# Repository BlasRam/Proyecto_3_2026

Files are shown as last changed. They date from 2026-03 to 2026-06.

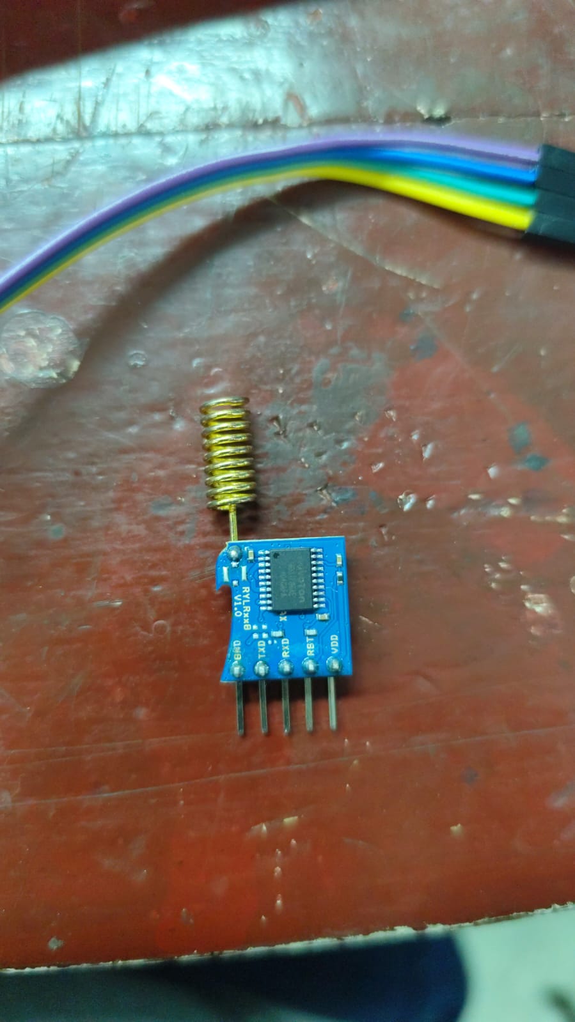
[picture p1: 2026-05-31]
Sistema_IAQ_LoRa/Sistema_IAQ_LoRa/images/2.jpeg

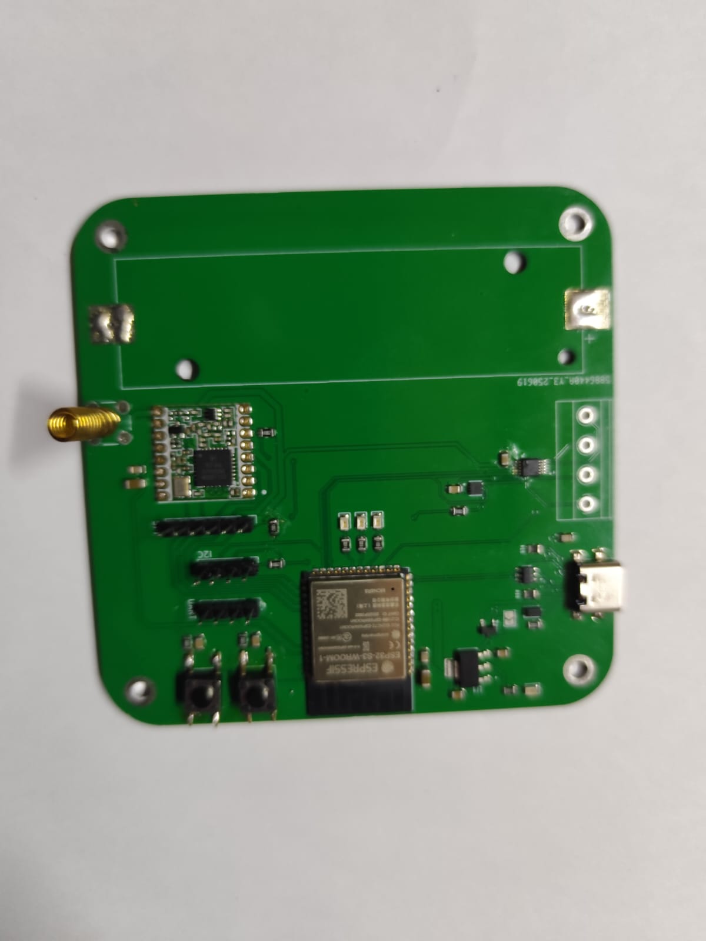
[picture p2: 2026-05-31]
Sistema_IAQ_LoRa/Sistema_IAQ_LoRa/images/4.jpeg

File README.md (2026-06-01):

# Sistema Experimental para el Monitoreo de la Calidad del Aire Interior (IAQ) y Variables Ambientales con Comunicación LoRa

## Descripción

Este repositorio contiene el desarrollo de un sistema experimental para el monitoreo de la calidad del aire interior (IAQ) y variables ambientales, con capacidad de comunicación inalámbrica mediante tecnología LoRa.

El proyecto está orientado al diseño y validación de una plataforma electrónica basada en **ESP32-S3**, integrando sensado ambiental, adquisición de señales, supervisión energética y transmisión de datos. La propuesta busca servir como base para futuras pruebas de hardware, adquisición de datos ambientales y validación de un sistema completo de monitoreo IAQ.

## Objetivo

Desarrollar una plataforma experimental capaz de:

- monitorear variables asociadas a la calidad del aire interior
- adquirir variables ambientales complementarias
- supervisar el estado energético del sistema
- transmitir información de manera inalámbrica mediante LoRa
- servir como base para futuras etapas de validación y escalabilidad

## Características principales

- Microcontrolador **ESP32-S3**
- Monitoreo de calidad del aire interior (**IAQ**)
- Medición de variables ambientales
- Comunicación **LoRa**
- Supervisión de batería y alimentación
- Diseño electrónico propio en desarrollo
- Arquitectura modular y escalable

## Estado del proyecto

Actualmente el proyecto se encuentra en etapa de:

- desarrollo del esquemático electrónico
- selección e integración de componentes
- definición de arquitectura de alimentación y comunicaciones
- preparación para diseño de PCB
- consolidación del prototipo experimental

## Arquitectura general

El sistema contempla los siguientes bloques principales:

- **Unidad de control:** ESP32-S3
- **Sensado ambiental e IAQ:** sensores para calidad del aire y variables ambientales
- **Comunicación inalámbrica:** módulo LoRa
- **Supervisión energética:** monitoreo de batería y consumo
- **Alimentación:** entrada USB, batería recargable y regulación de voltaje
- **Expansión:** puertos auxiliares para futuras integraciones

## Tecnologías y módulos considerados

Dependiendo de la iteración del prototipo, el sistema contempla o evalúa componentes como:

- **ESP32-S3-WROOM-1**
- **RFM95CW** o **RYLR998** para comunicación LoRa
- **ENS160 / AHT2X** para IAQ y variables ambientales
- **ADS1015** para adquisición analógica adicional
- **MAX17048** para monitoreo de batería
- **TP4056** para carga de batería
- reguladores de 3.3 V para alimentación estable del sistema

## Estructura del repositorio

```text
/
├── Software/          # Programacion (Codigos y Pruebas) del proyecto
├── docs/              # Documentación del proyecto
├── hardware/          # Esquemáticos, PCB, librerías y archivos de diseño
├── firmware/          # Código fuente del microcontrolador
├── images/            # Diagramas, capturas y recursos gráficos
├── datasheets/        # Hojas de datos de los componentes utilizados
└── README.md          # Descripción general del proyecto

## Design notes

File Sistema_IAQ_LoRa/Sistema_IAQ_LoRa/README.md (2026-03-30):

# Sistema Experimental para el Monitoreo de la Calidad del Aire Interior (IAQ) y Variables Ambientales con Comunicación LoRa

## Descripción
Este repositorio contiene el desarrollo de un sistema experimental para el monitoreo de la calidad del aire interior (IAQ) y variables ambientales, con capacidad de comunicación inalámbrica mediante tecnología LoRa.

El proyecto está orientado al diseño y validación de una plataforma electrónica basada en ESP32-S3, integrando sensado ambiental, adquisición de señales, supervisión energética y transmisión de datos. La propuesta busca servir como base para futuras pruebas de hardware, adquisición de datos ambientales y validación de un sistema completo de monitoreo IAQ.

## Estructura del repositorio
```text
.
├── docs/                # Documentación del proyecto
├── hardware/            # Esquemáticos, PCB, librerías y archivos de fabricación
│   ├── kicad/           # Proyecto principal de KiCad
│   ├── libraries/       # Footprints, símbolos y modelos 3D adicionales
│   └── manufacturing/   # Archivos de producción (Gerbers, BOM, posiciones, etc.)
├── firmware/            # Código fuente del microcontrolador
├── images/              # Diagramas, capturas y recursos gráficos
├── datasheets/          # Hojas de datos de los componentes utilizados
└── README.md            # Descripción general del proyecto
```

## Integrantes
- Blas Antonio Ramirez Benitez
- Pedro Daniel Vera Ramirez
- Pablo Junior Otazu Lujan

## Estado del proyecto
Actualmente el proyecto se encuentra en etapa de desarrollo del prototipo electrónico, consolidación del esquemático y organización de los archivos de diseño para futuras pruebas y fabricación.

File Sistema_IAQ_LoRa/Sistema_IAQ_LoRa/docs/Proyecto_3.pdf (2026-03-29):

## Universidad Nacional de Asunción Facultad de Ingeniería Carrera de Ingeniería Mecatrónica

## Proyecto 3

# Sistema Experimental para el Monitoreo de la Calidad del Aire Interior (IAQ) y Variables Ambientales con Comunicación LoRa

### Integrantes

### Blas Antonio Ramirez Benitez

### Pedro Daniel Vera Ramirez

### Pablo Junior Otazu Lujan

Octavo semestre

## Resumen ejecutivo

El presente proyecto plantea el desarrollo de un sistema experimental orientado al monitoreo de la calidad del aire interior (Indoor Air Quality, IAQ), integrando sensado ambiental, adquisición de señales, supervisión energética y comunicación inalámbrica. La versión actual del prototipo se basa en un microcontrolador ESP32-S3-WROOM-1-N4R2 como núcleo de control, acompañado por un transceptor LoRa RFM95CW para comunicación inalámbrica, un convertidor analógico-digital ADS1015 para ampliar la capacidad de lectura de señales analógicas, un monitor de batería MAX17048 y una arquitectura de alimentación que incluye entrada USB-C, conmutación USB-batería y regulación LDO a 3.3 V.

Además de la configuración actual, el proyecto contempla como configuración final prevista la incorporación del sensor ENS160/AHT2X para medición de variables relacionadas con la calidad del aire interior, así como la posibilidad de utilizar un módulo RYLR998 como alternativa de comunicación LoRa en caso de no disponer del transceptor actualmente seleccionado. El trabajo se encuentra en etapa de consolidación del prototipo electrónico, con esquemáticos organizados por bloques y una estimación preliminar de costos. Los resultados esperados incluyen la obtención de una plataforma funcional, compacta y escalable que permita realizar futuras pruebas físicas, adquirir datos ambientales y servir como base para validaciones posteriores del sistema.

## Abstract

Este proyecto presenta el desarrollo de un sistema experimental para el monitoreo de la calidad del aire interior (IAQ), integrando sensado ambiental, adquisición de señales, supervisión energética y comunicación inalámbrica. El prototipo actual está basado en un microcontrolador ESP32-S3-WROOM-1-N4R2 como unidad principal de control, junto con un transceptor LoRa RFM95CW para comunicación inalámbrica, un convertidor analógico-digital ADS1015 para ampliar la adquisición de señales analógicas, un monitor de batería MAX17048 y una arquitectura de alimentación que incluye entrada USB-C, conmutación entre USB y batería, y regulación a 3.3 V mediante un regulador LDO.

Además de la configuración actual, el sistema final previsto contempla la integración de un sensor ENS160/AHT2X para la medición de la calidad del aire interior y de variables ambientales, así como la posibilidad de utilizar un módulo RYLR998 como solución LoRa alternativa en caso de que el transceptor originalmente seleccionado no esté disponible. En la actualidad, el proyecto se encuentra en la fase de prototipado electrónico y consolidación del esquemático, con los bloques funcionales ya definidos y una estimación preliminar de costos disponible. El resultado esperado es una plataforma compacta y escalable, capaz de servir como base para futuras pruebas de hardware, adquisición de datos ambientales y posterior validación del sistema completo de monitoreo IAQ.

## Estado del arte

Los sistemas de monitoreo de calidad del aire interior basados en IoT combinan habitualmente sensores de bajo costo, microcontroladores y enlaces inalámbricos para obtener datos en tiempo real y mejorar el control ambiental en espacios cerrados.

Marques y Pitarma presentan una revisión de sistemas IAQ para entornos inteligentes y resaltan la importancia de integrar sensado, procesamiento y comunicación en plataformas compactas [1].

Mota et al. desarrollan una arquitectura IoT para supervisión de IAQ, mostrando que los sistemas embebidos conectados son adecuados para monitoreo continuo en interiores [2].

González et al. validan el uso de LoRa en redes de sensores ambientales y de detección de eventos, respaldando su empleo cuando se requieren enlaces de largo alcance y bajo consumo [3].

Pietraru et al. analizan sensores MOS para VOC/TVOC en ambientes interiores y muestran que son apropiados como indicadores indirectos de calidad del aire dentro de arquitecturas experimentales o aplicadas [4].

Por su parte, la familia ENS160 ha sido desarrollada específicamente para aplicaciones IAQ y ofrece variables procesadas como eCO2, TVOC e índices de calidad del aire [5].

## Descripción

El proyecto consiste en el diseño de una plataforma experimental de monitoreo de calidad del aire interior, concebida como una base electrónica escalable para adquisición de variables ambientales, supervisión de señales analógicas, monitoreo energético y transmisión inalámbrica. El núcleo actual del sistema es el ESP32-S3-WROOM-1-N4R2, encargado de coordinar la lectura de periféricos y gestionar las interfaces de comunicación.

La versión prototipo actual contempla los bloques MCU, LoRa, ADC externo, monitor de batería, alimentación USB-batería, regulador, botones de control, LEDs de depuración y puertos de expansión. Como evolución prevista del sistema, se integrará un módulo ENS160/AHT2X para medir variables asociadas a calidad del aire interior y variables ambientales. En cuanto a la comunicación, se mantiene el uso actual del RFM95CW como transceptor LoRa, pero se considera al RYLR998 como alternativa viable de implementación si el componente principal no se encuentra disponible.

La motivación del proyecto radica en disponer de una plataforma propia para estudiar y experimentar con monitoreo IAQ, permitiendo tanto el aprendizaje en diseño electrónico como la futura validación de un sistema real de adquisición y transmisión de datos ambientales.

## Objetivos

General

Diseñar e implementar un sistema experimental de monitoreo de la calidad del aire interior (IAQ) mediante sensor MOS y variables ambientales, con capacidad de adquisición, supervisión energética y transmisión inalámbrica de datos.

Específicos

- Diseñar la arquitectura electrónica del sistema, incluyendo bloques de alimentación, control, adquisición y comunicación.
- Integrar un ESP32-S3 con periféricos externos para lectura de señales analógicas, monitoreo de batería y comunicación inalámbrica.
- Implementar una arquitectura de alimentación con batería recargable, entrada USB-C, selección de fuente y regulación estable a 3.3 V.
- Preparar el sistema para la futura integración del sensor ENS160/AHT2X y para la evaluación de módulos LoRa alternativos según disponibilidad.
- Desarrollar el prototipo electrónico como base para la futura fabricación de la PCB y la posterior etapa de pruebas físicas e integradas.

## Esquema general del proyecto

La Figura 1 muestra el esquema general del prototipo actual y la configuración final prevista. La arquitectura organiza el sistema en bloques funcionales: entrada USB-C, selector USB-batería, regulación a 3.3 V, MCU, comunicación LoRa, adquisición analógica, monitor de batería, puertos de expansión y módulo IAQ previsto para la versión final.

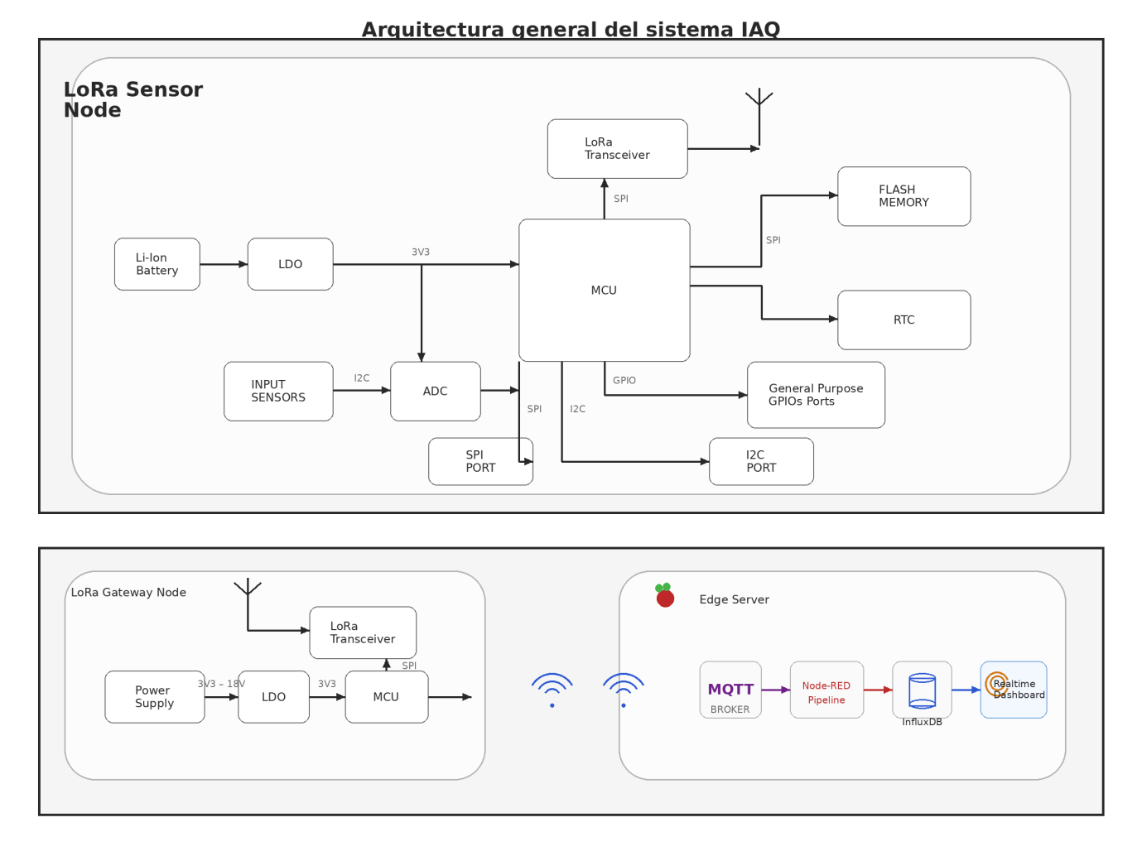
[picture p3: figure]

Figura 1. Esquema general del prototipo y configuración final prevista.

## 6.1 Product Breakdown Structure

1. Bloque MCU: ESP32-S3-WROOM-1-N4R2, alimentación a 3.3 V, USB nativo, botones de control y LEDs.
2. Bloque LoRa: RFM95CW como solución actual de comunicación y RYLR998 como alternativa contemplada.
3. Bloque de adquisición: ADS1015 para ampliación de entradas analógicas y puertos de expansión I2C/UART/SPI.
4. Bloque de monitoreo energético: MAX17048 para supervisión del estado de la batería.
5. Bloque de alimentación: USB-C, selector USB-batería, batería y regulador LDO a 3.3 V.
6. Bloque de sensado futuro: Integración prevista del módulo ENS160/AHT2X para IAQ y variables ambientales.

## Diseños

Electrónico

El diseño electrónico está organizado por bloques, lo que permite separar claramente funciones de alimentación, adquisición, comunicación y control. La Figura 2 presenta el bloque MCU, donde el ESP32-S3 se alimenta a 3.3 V, incorpora desacoples locales y expone líneas para comunicación LoRa, I2C, ADC y LEDs. La Figura 3 muestra el transceptor LoRa actual basado en RFM95CW, mientras que las Figuras 4 y 5 corresponden al monitor de batería MAX17048 y al ADC ADS1015, respectivamente. Las Figuras 6 y 7 muestran los bloques de entrada USB-C y de regulación LDO. Finalmente, las Figuras 8 y 9 muestran los botones de control y los elementos auxiliares de alimentación, expansión y depuración.

Descripción de bloques del esquemático actual

Bloque MCU: El ESP32-S3-WROOM-1-N4R2 constituye la unidad central de procesamiento. Este bloque concentra el control del sistema, la lógica de adquisición, la comunicación con periféricos y el manejo de señales de usuario. Se alimenta a 3.3 V e incluye desacoples locales para mejorar la estabilidad eléctrica.

Bloque LoRa: El transceptor RFM95CW implementa la comunicación inalámbrica LoRa del prototipo actual mediante interfaz SPI. El diseño prevé además una alternativa basada en RYLR998, que podría emplearse posteriormente si se modifica la estrategia de comunicación o la disponibilidad de componentes.

Bloque de alimentación USB-batería: Este bloque administra la entrada desde USB-C y la selección de fuente entre VBUS y la batería. El uso de un diodo Schottky y un MOSFET canal P permite alimentar el sistema desde USB cuando está disponible y recurrir a la batería cuando no hay fuente externa.

Bloque regulador: El regulador LDO LDL1117S33R genera la línea principal de 3.3 V del sistema a partir de la tensión de entrada VIN. Se incluyen capacitores de entrada y salida para filtrar ruido, estabilizar la regulación y mantener una alimentación adecuada para el microcontrolador y los periféricos.

Bloque ADC: El ADS1015 amplía la capacidad de medición analógica del sistema. Mediante interfaz I2C, este convertidor permite adquirir señales externas adicionales con resolución adecuada para pruebas y expansión del prototipo.

Bloque monitor de batería: El MAX17048 se encarga del seguimiento del estado de carga de la batería. Este circuito permite conocer el nivel energético disponible y generar una señal de alerta, aportando información útil para autonomía, gestión energética y futuras estrategias de bajo consumo.

Bloque USB-C y protección: El conector USB-C proporciona la entrada de alimentación y la interfaz física de programación. La protección ESD y los elementos pasivos asociados reducen el riesgo de daño por descargas electrostáticas y mejoran la robustez del sistema frente a conexión y desconexión frecuente.

Bloque de botones y LEDs: Los pulsadores BOOT y RESET permiten entrar en modo de programación y reiniciar el sistema, respectivamente. Los LEDs de depuración brindan indicación visual del estado del prototipo y facilitan la verificación rápida del funcionamiento básico durante las pruebas.

Bloque de expansión: Los puertos I2C, UART y SPI se dejaron accesibles para futuras ampliaciones. Esta decisión permite conectar módulos adicionales, sensores o herramientas de prueba sin modificar profundamente la arquitectura principal.

Bloque de sensado IAQ previsto: Como evolución del prototipo se contempla la integración de un módulo ENS160/AHT2X, que permitiría medir variables vinculadas con calidad de aire interior y condiciones ambientales, complementando la adquisición electrónica ya implementada.

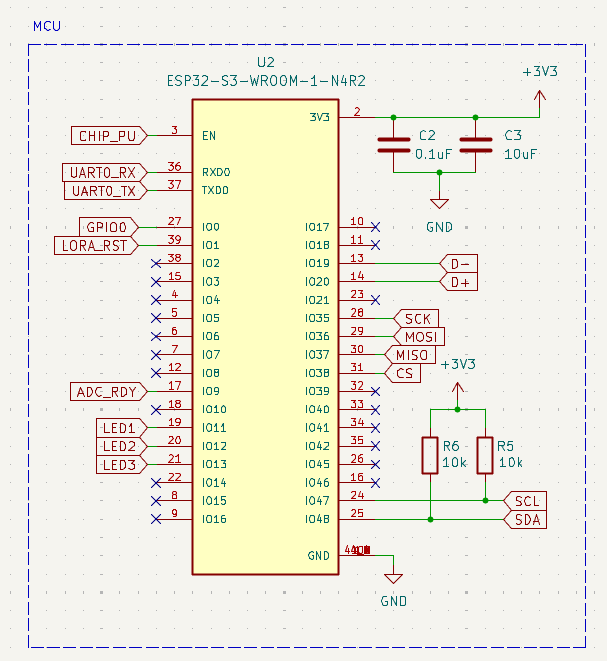
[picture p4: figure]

Figura 2. Bloque MCU basado en ESP32-S3-WROOM-1-N4R2.

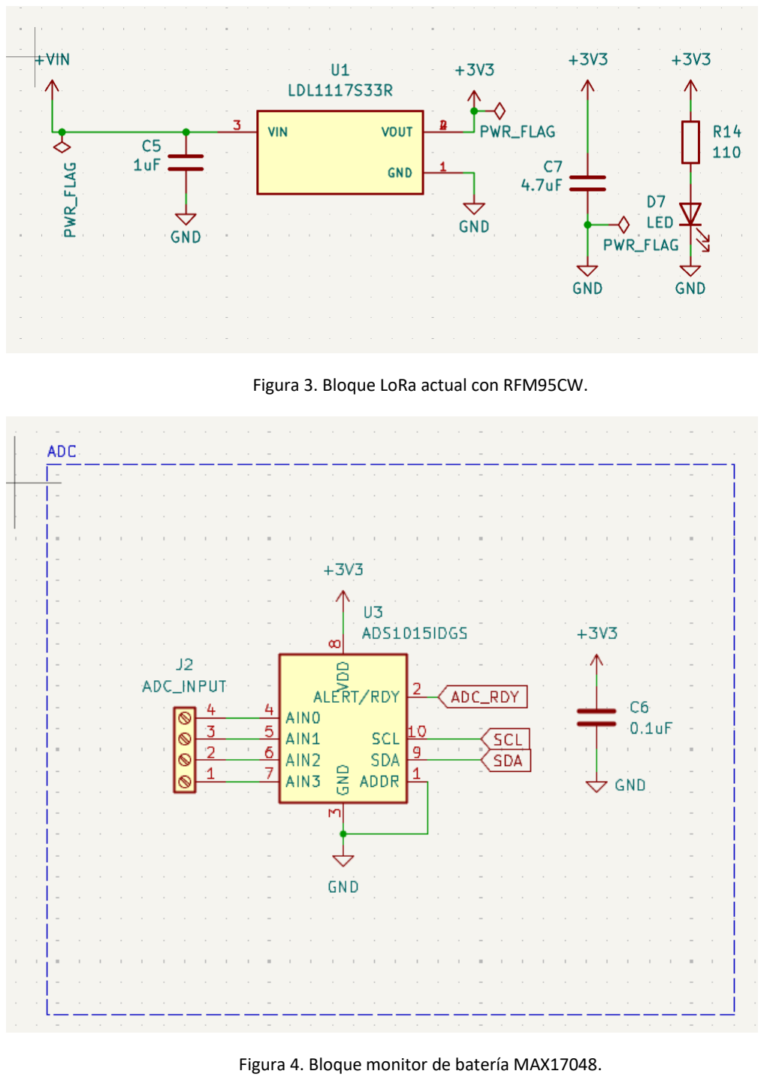
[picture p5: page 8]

Figura 3. Bloque LoRa actual con RFM95CW.

Figura 4. Bloque monitor de batería MAX17048.

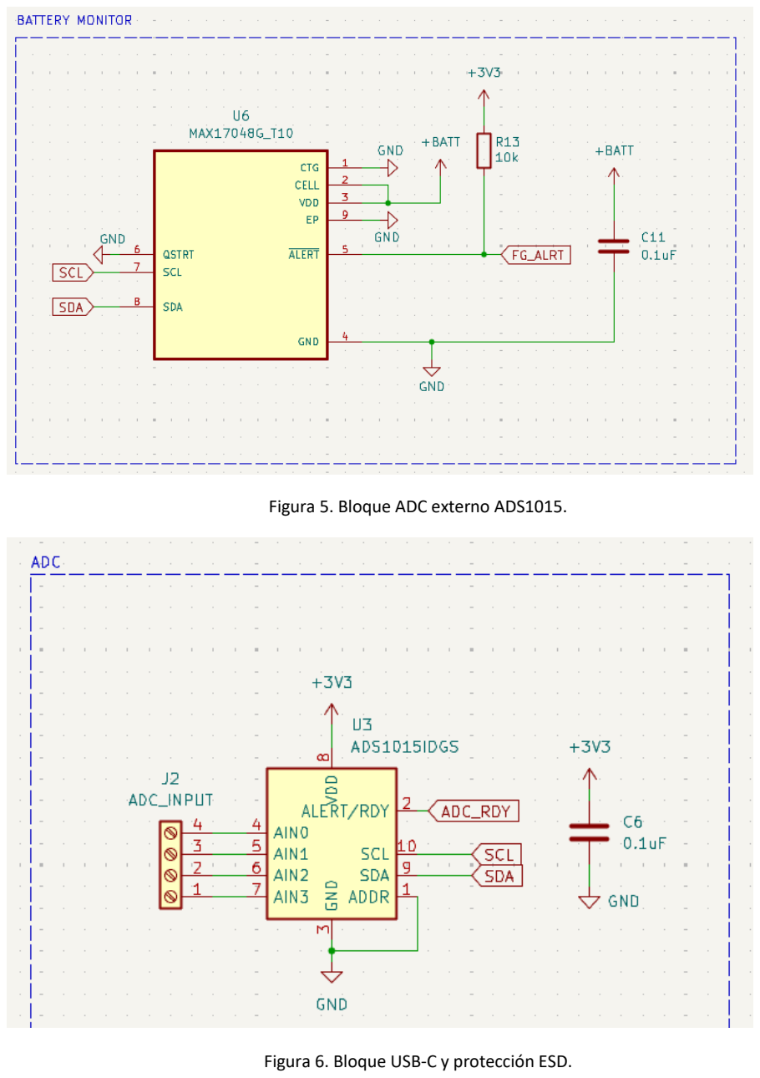
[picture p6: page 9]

Figura 5. Bloque ADC externo ADS1015.

Figura 6. Bloque USB-C y protección ESD.

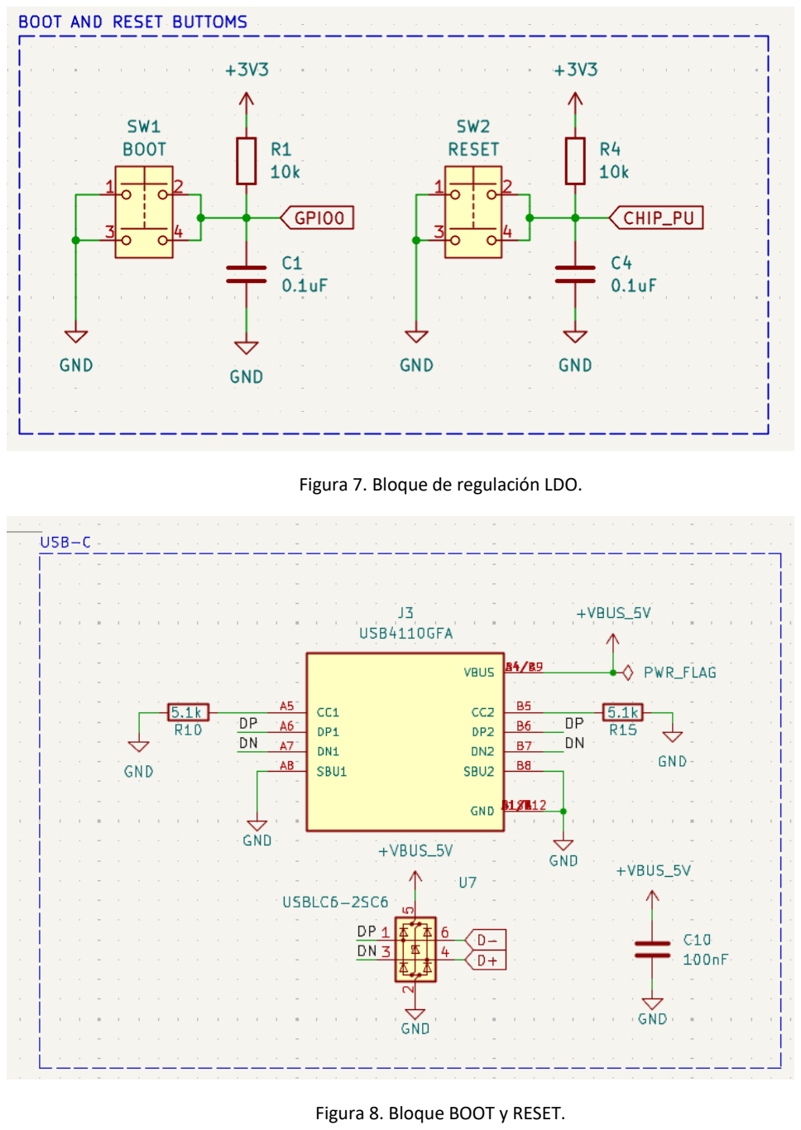
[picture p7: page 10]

Figura 7. Bloque de regulación LDO.

Figura 8. Bloque BOOT y RESET.

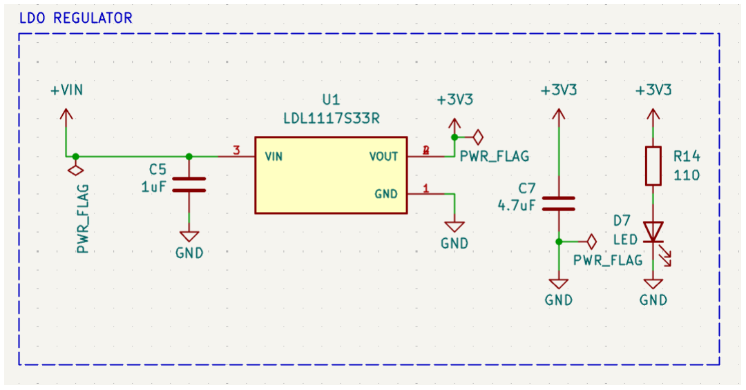
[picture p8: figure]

Figura 9. Bloques auxiliares de alimentación, depuración y expansión.

Mecánico

En esta etapa no se dispone aún de un diseño mecánico definitivo. Se prevé el desarrollo futuro de un encapsulado o caja protectora que permita el montaje del sistema en entornos interiores y garantice ventilación adecuada hacia el futuro sensor de calidad del aire.

Interfaz

La interfaz de usuario se considera como desarrollo futuro. Se prevé la implementación de una interfaz local o remota que permita visualizar variables de alimentación, estado del sistema, señales analógicas y parámetros de calidad del aire una vez integrado el sensor correspondiente.

## Costos

Materiales y herramientas compradas / incremental

Ítem | Cantidad | Precio unitario (USD) | Precio total (USD)
P-channel MOSFET AO3407A | 1 | 0.0362 | 0.0362
Schottky diode 1N5819WS | 1 | 0.0090 | 0.0090
Single-color LEDs 0805 | 3 | 0.0094 | 0.0282
USB Type-C connector | 1 | 1.24 | 1.24
Ceramic capacitors MLCC 0.47 µF | 4 | 0.0200 | 0.0800
Resistores SMD 0805 10 kΩ | 6 | 0.0023 | 0.0138
Resistores SMD 110 Ω 0805 | 4 | 0.0030 | 0.0120
Capacitores cerámicos 0.1 µF | 4 | 0.0040 | 0.0160
Capacitores cerámicos 1 µF | 4 | 0.0066 | 0.0264
Capacitores cerámicos 4.7 µF | 4 | 0.0160 | 0.0640
ESP32-S3-WROOM-1 | 2 | 3.6439 | 7.2878
RFM95-915 MHz | 2 | 22.82 | 45.64
Servicio fabricación PCB | 1 | 2.00 | 2.00
Total estimado | | | USD 66.45

Los costos anteriores corresponden a una estimación preliminar del prototipo actual con base en la lista de componentes seleccionados y el servicio de fabricación previsto.

Materiales y herramientas prestadas / existentes

Ítem | Cantidad
Computadora de diseño | 1
Software KiCad | 1
Herramientas de soldadura | 1 juego
Instrumentación básica de laboratorio | Por definir

## Resultados parciales y finales

Resultados parciales

Hasta el momento, el proyecto cuenta con una definición clara de la arquitectura electrónica, esquemáticos por bloques funcionales, selección preliminar de componentes y estimación inicial de costos. Se han estructurado el bloque MCU, el bloque LoRa actual, el bloque de adquisición analógica, el monitor de batería, el subsistema de alimentación, los puertos de expansión y los botones de control.

Resultados finales

Aún no se han realizado pruebas físicas del sistema, debido a que la placa todavía no ha sido fabricada ni ensamblada. En consecuencia, no se dispone todavía de resultados numéricos, tablas de medición o gráficas de desempeño. La etapa de resultados finales se abordará una vez completada la fabricación de la PCB, el montaje de componentes y la puesta en marcha del prototipo.

Pruebas previstas

- Verificación del arranque y programación del ESP32-S3 mediante USB nativo.
- Medición de la tensión regulada a 3.3 V y validación del bloque de alimentación.
- Lectura del monitor de batería MAX17048 y comprobación del estado energético.
- Lectura de señales analógicas mediante ADS1015.
- Pruebas de comunicación con el módulo LoRa seleccionado.
- Integración futura del módulo ENS160/AHT2X y evaluación de sus variables ambientales.

## Conclusiones y recomendaciones finales

El proyecto presenta un avance importante en la etapa de diseño, con una arquitectura modular y escalable que integra procesamiento, adquisición analógica, monitoreo energético y comunicación inalámbrica. La organización del esquemático por bloques ha permitido establecer una base sólida para la siguiente etapa de diseño PCB. La selección del ESP32-S3 como unidad principal es adecuada para una plataforma experimental de este tipo, mientras que los bloques auxiliares amplían la funcionalidad del prototipo actual.

Entre las mejoras futuras se incluyen la integración definitiva del ENS160/AHT2X, la evaluación de la alternativa RYLR998, el desarrollo de una interfaz de visualización y el diseño mecánico de un encapsulado apropiado para uso en ambientes interiores.

## Bibliografía

[1] G. Marques and R. Pitarma, “Indoor Air Quality Monitoring Systems for Enhanced Living Environments: A Review toward Sustainable Smart Cities,” Sustainability, vol. 12, no. 10, 2020.
[2] A. Mota et al., “Implementation of an Internet of Things Architecture to Monitor Indoor Air Quality Parameters,” Sensors, vol. 25, no. 6, 2025.
[3] E. González et al., “LoRa Sensor Network Development for Air Quality Monitoring or Detecting Gas Leakage Events,” Sensors, vol. 20, no. 21, 2020.
[4] R. N. Pietraru et al., “Easy-to-Use MOX-Based VOC Sensors for Efficient Indoor Air Quality Monitoring,” Sensors, vol. 24, no. 8, 2024.
[5] ScioSense, “ENS160 Datasheet,” 2023.
[6] Espressif Systems, “ESP32-S3-WROOM-1 / WROOM-1U Datasheet.”
[7] HopeRF, “RFM95CW LoRa Transceiver Module.”
[8] Analog Devices, “MAX17048/MAX17049 Fuel Gauge Datasheet.”
[9] Texas Instruments, “ADS1015 Datasheet.”

## Anexos

- Esquemático del bloque MCU.
- Esquemático del bloque LoRa actual.
- Esquemático del bloque ADC.
- Esquemático del monitor de batería.
- Esquemático del bloque USB-C.
- Esquemático del regulador LDO.
- Esquemático de botones BOOT y RESET.
- Esquemáticos auxiliares de alimentación, puertos y LEDs.
- Tabla preliminar de costos.

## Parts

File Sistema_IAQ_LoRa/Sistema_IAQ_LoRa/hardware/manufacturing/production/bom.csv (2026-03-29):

Designator | Footprint | Quantity | Value | LCSC Part #
BT1 | BatteryHolder_Keystone_1042_1x18650 | 1 | 1042
C1, C11, C2, C4, C6, C8 | 0805 | 6 | 0.1uF
C10 | 0805 | 1 | 100nF
C3, C9 | 0805 | 2 | 10uF
C5 | 0805 | 1 | 1uF
C7 | 0805 | 1 | 4.7uF
D2, D5, D6, D7 | 0805 | 4 | LED
D3 | 0805 | 1 | D_Schottky
J1 | SAMTEC_SMA-J-P-X-RA-TH1 | 1 | SMA-J-P-X-RA-TH1
J2 | TerminalBlock_Phoenix_MKDS-1,5-4-5.08_1x04_P5.08mm_Horizontal | 1 | ADC_INPUT
J3 | GCT_USB4110GFA | 1 | USB4110GFA
J6 | PinHeader_1x04_P2.54mm_Vertical | 1 | I2C PORT
J7 | PinHeader_1x04_P2.54mm_Vertical | 1 | UART
J8 | PinHeader_1x06_P2.54mm_Vertical | 1 | SPI
JP1 | SolderJumper-2_P1.3mm_Open_TrianglePad1.0x1.5mm | 1 | Jumper_2_Open
Q1 | SOT-23 | 1 | Q_PMOS_DGS
R1, R12, R13, R4, R5, R6, R8 | 0805 | 7 | 10k
R10, R15 | 0805 | 2 | 5.1k
R11, R14, R7, R9 | 0805 | 4 | 110
SW1 | SW_TS04-66-43-BK-100-SMT | 1 | BOOT
SW2 | SW_TS04-66-43-BK-100-SMT | 1 | RESET
U1 | SOT230P700X180-4N | 1 | LDL1117S33R
U2 | XCVR_ESP32-S3-WROOM-1-N4R2 | 1 | ESP32-S3-WROOM-1-N4R2
U3 | SOP50P490X110-10N | 1 | ADS1015IDGS
U5 | XCVR_RFM95W-868S2 | 1 | RFM95CW
U6 | SON50P200X200X80-9N | 1 | MAX17048G_T10
U7 | SOT95P280X145-6N | 1 | USBLC6-2SC6

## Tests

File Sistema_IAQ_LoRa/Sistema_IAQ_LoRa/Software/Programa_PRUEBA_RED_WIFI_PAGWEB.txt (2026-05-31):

#include <WiFi.h>
#include <WebServer.h>

// ======================= WIFI =======================
const char* ssid = "Nombre de la RED";
const char* password = "Contraseña de la RED";

// ======================= LEDS =======================
// Cambiar si estás usando otro ESP32
#define LED_WIFI 2

WebServer server(80);

void paginaPrincipal() {
  String html = "";

  html += "<!DOCTYPE html>";
  html += "<html>";
  html += "<head>";
  html += "<meta charset='UTF-8'>";
  html += "<meta name='viewport' content='width=device-width, initial-scale=1.0'>";
  html += "<meta http-equiv='refresh' content='5'>";
  html += "<title>Prueba WiFi ESP32</title>";
  html += "<style>";
  html += "body{font-family:Arial;text-align:center;background:#f0f0f0;}";
  html += ".card{background:white;width:350px;margin:auto;padding:20px;";
  html += "border-radius:15px;box-shadow:0px 0px 10px gray;}";
  html += "h1{color:#0066cc;}";
  html += "p{font-size:20px;}";
  html += "</style>";
  html += "</head>";
  html += "<body>";
  html += "<h1>Prueba WiFi ESP32</h1>";
  html += "<div class='card'>";
  html += "<p><b>Estado:</b> Conectado</p>";
  html += "<p><b>IP:</b> ";
  html += WiFi.localIP().toString();
  html += "</p>";
  html += "<p>Servidor web funcionando correctamente.</p>";
  html += "</div>";
  html += "</body>";
  html += "</html>";

  server.send(200, "text/html", html);
}

void setup() {
  pinMode(LED_WIFI, OUTPUT);
  digitalWrite(LED_WIFI, LOW);

  Serial.begin(115200);
  delay(1000);

  Serial.println();
  Serial.println("==================================");
  Serial.println("PRUEBA WIFI + WEB SERVER");
  Serial.println("==================================");

  WiFi.mode(WIFI_STA);
  WiFi.begin(ssid, password);

  Serial.print("Conectando a WiFi");

  while (WiFi.status() != WL_CONNECTED) {
    delay(500);
    Serial.print(".");
    digitalWrite(LED_WIFI, !digitalRead(LED_WIFI));
  }

  digitalWrite(LED_WIFI, HIGH);

  Serial.println();
  Serial.println("WiFi conectado correctamente.");
  Serial.print("IP asignada: ");
  Serial.println(WiFi.localIP());

  server.on("/", paginaPrincipal);
  server.begin();

  Serial.println("Servidor web iniciado.");
  Serial.print("Abrir en navegador: http://");
  Serial.println(WiFi.localIP());
}

void loop() {
  server.handleClient();
}

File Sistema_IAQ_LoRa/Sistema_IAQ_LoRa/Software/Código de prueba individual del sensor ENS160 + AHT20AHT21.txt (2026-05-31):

#include <Wire.h>
#include <Adafruit_AHTX0.h>
#include "ScioSense_ENS160.h"

// ======================= I2C =======================
#define SDA_PIN 48
#define SCL_PIN 47

// Para ESP32 DevKit común usar:
// #define SDA_PIN 21
// #define SCL_PIN 22

// ======================= SENSORES =======================
Adafruit_AHTX0 aht;
ScioSense_ENS160 ens160(ENS160_I2CADDR_1);

// ======================= VARIABLES =======================
float temperatura = 0;
float humedad = 0;

uint8_t aqi = 0;
uint16_t tvoc = 0;
uint16_t eco2 = 0;

bool aht_ok = false;
bool ens_ok = false;

void leerSensores() {
  if (aht_ok) {
    sensors_event_t hum;
    sensors_event_t temp;

    aht.getEvent(&hum, &temp);

    temperatura = temp.temperature;
    humedad = hum.relative_humidity;
  }

  if (ens_ok) {
    ens160.set_envdata(temperatura, humedad);
    ens160.measure(true);

    aqi = ens160.getAQI();
    tvoc = ens160.getTVOC();
    eco2 = ens160.geteCO2();
  }
}

void setup() {
  Serial.begin(115200);
  delay(2000);

  Serial.println();
  Serial.println("==================================");
  Serial.println("PRUEBA SENSOR ENS160 + AHT20/AHT21");
  Serial.println("==================================");

  Wire.begin(SDA_PIN, SCL_PIN);

  Serial.print("SDA: GPIO");
  Serial.println(SDA_PIN);

  Serial.print("SCL: GPIO");
  Serial.println(SCL_PIN);

  // -------- AHT20/AHT21 --------
  Serial.print("Inicializando AHT20/AHT21... ");

  if (aht.begin(&Wire)) {
    Serial.println("OK");
    aht_ok = true;
  } else {
    Serial.println("ERROR");
    aht_ok = false;
  }

  // -------- ENS160 --------
  Serial.print("Inicializando ENS160... ");

  ens160.begin();

  if (ens160.available()) {
    Serial.println("OK");
    ens_ok = true;

    Serial.print("Version ENS160: ");
    Serial.print(ens160.getMajorRev());
    Serial.print(".");
    Serial.print(ens160.getMinorRev());
    Serial.print(".");
    Serial.println(ens160.getBuild());

    ens160.setMode(ENS160_OPMODE_STD);
  } else {
    Serial.println("ERROR");
    ens_ok = false;
  }

  Serial.println("==================================");
}

void loop() {
  leerSensores();

  Serial.println();
  Serial.println("============== DATOS ==============");

  Serial.print("Temperatura: ");
  Serial.print(temperatura, 2);
  Serial.println(" °C");

  Serial.print("Humedad: ");
  Serial.print(humedad, 2);
  Serial.println(" %");

  Serial.print("AQI: ");
  Serial.println(aqi);

  Serial.print("TVOC: ");
  Serial.print(tvoc);
  Serial.println(" ppb");

  Serial.print("eCO2: ");
  Serial.print(eco2);
  Serial.println(" ppm");

  Serial.println("===================================");

  delay(5000);
}

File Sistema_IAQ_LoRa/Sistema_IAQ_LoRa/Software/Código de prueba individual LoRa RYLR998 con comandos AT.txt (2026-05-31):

// =====================================================
// ESP32 + RYLR998
// Prueba individual con comandos AT
// =====================================================
//
// Conexión:
// ESP32 RX2 GPIO16  <- TXD del RYLR998
// ESP32 TX2 GPIO17  -> RXD del RYLR998
// GND común
// VDD del RYLR998 -> 3V3

#define LORA_RX 16
#define LORA_TX 17

void setup() {
  Serial.begin(115200);
  delay(1000);

  Serial2.begin(115200, SERIAL_8N1, LORA_RX, LORA_TX);

  Serial.println();
  Serial.println("==================================");
  Serial.println("ESP32 listo para comunicarse con RYLR998");
  Serial.println("==================================");
  Serial.println("Escribi comandos AT en el Monitor Serial.");
  Serial.println("Configurar Monitor Serial:");
  Serial.println("Baudios: 115200");
  Serial.println("Final de linea: Both NL & CR");
  Serial.println();
  Serial.println("Comandos de prueba:");
  Serial.println("AT");
  Serial.println("AT+ADDRESS?");
  Serial.println("AT+NETWORKID?");
  Serial.println("AT+BAND?");
  Serial.println("AT+PARAMETER?");
  Serial.println("==================================");
}

void loop() {
  // Datos que vienen del LoRa hacia el Monitor Serial
  while (Serial2.available()) {
    char c = Serial2.read();
    Serial.write(c);
  }

  // Datos que escribís en el Monitor Serial hacia el LoRa
  while (Serial.available()) {
    char c = Serial.read();
    Serial2.write(c);
  }
}

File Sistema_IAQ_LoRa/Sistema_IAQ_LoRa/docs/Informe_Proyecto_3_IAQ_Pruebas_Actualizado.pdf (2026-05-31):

### Universidad Nacional de Asunción Facultad de Ingeniería Carrera de Ingeniería Mecatrónica

Proyecto 3

# Sistema Experimental para el Monitoreo de la Calidad del Aire Interior (IAQ) y Variables Ambientales con Comunicación LoRa

Informe de montaje, pruebas y validación parcial del prototipo

Integrantes

Blas Antonio Ramirez Benitez

Pedro Daniel Vera Ramirez

Pablo Junior Otazu Lujan

Octavo semestre

2026

## Resumen ejecutivo

El presente informe actualiza el estado del Sistema Experimental para el Monitoreo de la Calidad del Aire Interior (IAQ) y Variables Ambientales con Comunicación LoRa. En la etapa anterior el proyecto se encontraba principalmente en fase de diseño electrónico, con una arquitectura basada en ESP32-S3, comunicación LoRa, adquisición de señales y sensado ambiental previsto. En esta etapa se avanzó hacia el montaje físico de las PCBs, pruebas de alimentación, programación, lectura de sensores, visualización web y ensayos preliminares de comunicación inalámbrica.

Se montaron dos placas desarrolladas por el grupo mediante pasta de soldar, stencil y horno de reflow. Ambas placas presentaron un problema de reconocimiento USB para programación directa desde Windows; sin embargo, se comprobó que podían alimentarse correctamente por USB y ejecutar programas cargados previamente por UART. Para continuar las pruebas se utilizó una placa ESP32 funcional externa como emisor, conectada al sensor ENS160 + AHT20/AHT21, y una de las placas desarrolladas como receptora.

El sistema ya permite medir temperatura, humedad, AQI, TVOC y eCO2, visualizar los datos mediante una página web local y validar la transmisión WiFi. La comunicación LoRa UART RYLR998 se encuentra en etapa de prueba: se logró una comunicación parcial mediante comandos AT, pero uno de los módulos presentó una falla de hardware, por lo que se requiere conseguir otro módulo para completar la validación punto a punto.

## Objetivo del informe

Documentar el procedimiento de montaje y horneado de las PCBs, los problemas encontrados y sus soluciones, los avances de programación y los resultados obtenidos en pruebas aisladas de sensores, actuadores e interfaces de comunicación.

## 1. Contexto del proyecto y arquitectura utilizada

El proyecto mantiene el mismo enfoque general planteado en el informe anterior: desarrollar una plataforma experimental para monitoreo de calidad de aire interior, variables ambientales y comunicación inalámbrica. La arquitectura inicial consideraba un ESP32-S3-WROOM-1-N4R2 como núcleo de control, un transceptor LoRa RFM95CW mediante SPI, un ADS1015 para adquisición analógica, un MAX17048 para monitoreo de batería y un sensor ENS160/AHT2X como módulo de sensado IAQ.

Durante la etapa de pruebas se realizó una modificación práctica: se decidió avanzar con el módulo RYLR998 UART como solución LoRa definitiva, en reemplazo del RFM95CW SPI, debido principalmente a disponibilidad y facilidad de integración mediante comandos AT por UART.

## 2. Procedimiento de montaje y horneado de las PCBs

Se montaron en total dos placas desarrolladas por el grupo. La intención inicial era utilizar una como emisor y otra como receptor dentro del sistema IAQ. El montaje de componentes SMD se realizó utilizando pasta de soldar, stencil y horno de reflow.

El procedimiento seguido fue el siguiente:

1. Revisión inicial de las PCBs y preparación del área de trabajo.
2. Alineación del stencil sobre la PCB para aplicar pasta de soldar en los pads SMD.
3. Aplicación de pasta de soldar mediante stencil.
4. Colocación de componentes SMD sobre la placa, verificando orientación y ubicación.
5. Horneado de la PCB para realizar el proceso de reflow.
6. Enfriamiento natural de la placa después del proceso térmico.
7. Inspección visual y revisión con microscopio de componentes críticos y orientaciones.
8. Corrección de puentes de soldadura mediante cautín y chupa estaño.
9. Soldadura manual de headers y botones con cautín.

Se soldaron los componentes principales de la placa mediante reflow. Los headers y botones fueron soldados posteriormente con cautín, debido a que resultaba más conveniente montarlos manualmente. No se observaron componentes desplazados después del horneado.

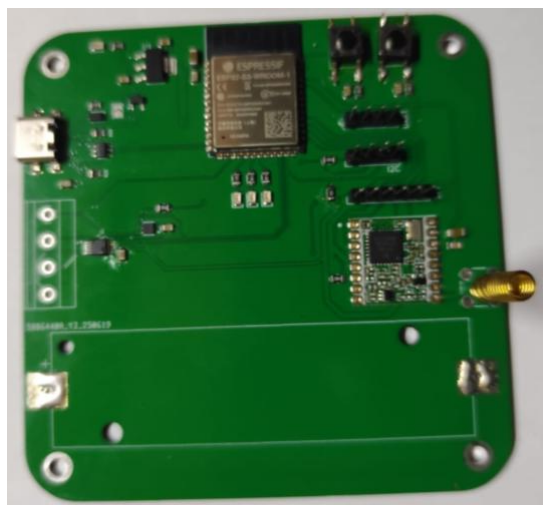
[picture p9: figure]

Figura 2. PCB montada utilizada durante las pruebas del sistema IAQ.

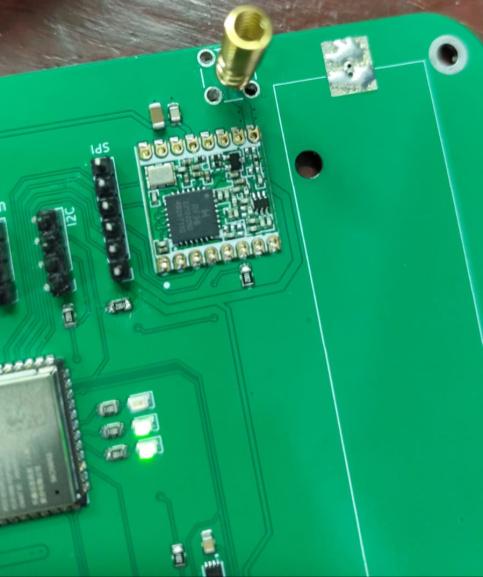
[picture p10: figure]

Figura 3. Vista de montaje de la placa y módulo de comunicación durante las pruebas.

## 2.1 Recomendación

En esta etapa no se realizó una medición previa de cortocircuito entre 3.3 V y GND antes de alimentar la placa. Como mejora para futuros montajes, se recomienda medir con multímetro la continuidad entre las líneas principales de alimentación, especialmente entre 3.3 V y GND, antes de energizar el circuito. También se recomienda verificar continuidad en líneas críticas como TX, RX, EN, GPIO0, D+ y D- del USB.

## 3. Problemas encontrados y soluciones aplicadas

Durante el montaje y puesta en marcha se identificaron problemas de soldadura, programación, comunicación USB y comunicación inalámbrica. La Tabla 1 resume los principales inconvenientes.

Problema | Causa probable | Solución aplicada o pendiente
Puentes de soldadura | Exceso de pasta o separación reducida entre pads | Corrección con cautín y chupa estaño; inspección posterior con microscopio.
No reconocimiento USB en ambas placas desarrolladas | Posible problema en líneas USB D+/D-, conector, soldadura o configuración USB CDC | Programación alternativa por UART usando otro ESP32. La alimentación por USB funciona correctamente.
Dificultad para usar Monitor Serial en la placa desarrollada | El UART se usaba para programación y pruebas | Visualización mediante servidor web y uso de Leds como indicadores.
Sensor no detectado al inicio | Pines I2C incorrectos para el ESP32 utilizado | Corrección de SDA/SCL según la placa utilizada.
Error de librería ENS160 | Uso de librería no compatible con el módulo disponible | Uso de ScioSense_ENS160 junto con Adafruit_AHTX0.
mDNS placa-aire. local no disponible | Limitación de la red o resolución local | Uso directo de la IP asignada por la red.
LoRa UART incompleto | Falla de hardware en uno de los módulos RYLR998 | Se logró comunicación parcial por AT; queda pendiente conseguir otro módulo para completar pruebas.

Tabla 1. Problemas encontrados durante montaje, programación y pruebas.

## 3.1 Problema de reconocimiento USB

Las dos placas desarrolladas presentaron el mismo inconveniente: al conectarlas a Windows por USB, el sistema no las reconocía como dispositivo de programación. Esto impidió la carga directa del programa mediante USB. Es importante aclarar que el problema se presentó únicamente en el reconocimiento para programación, ya que las placas sí podían alimentarse por USB y ejecutar correctamente el programa previamente cargado por UART.

Como solución temporal, se utilizó otro ESP32 como adaptador USB-UART. Para programar la placa se conectaron TX, RX y GND, se colocó GPIO0 a GND para entrar en modo bootloader, se reinició la placa, se cargó el programa y luego se retiró GPIO0 de GND para ejecutar el código normalmente.

Queda pendiente revisar la soldadura del conector USB, continuidad de D+ y D-, posible inversión o error de conexión en estas líneas, configuración USB CDC y posibles detalles de diseño asociados al circuito USB del ESP32-S3.

## 3.2 Puentes de soldadura

Después del horneado se observaron algunos puentes de soldadura. Estos fueron corregidos con chupa estaño y cautín. No se detectaron problemas de componentes movidos durante el proceso de reflow.

## 3.3 Problema con módulo LoRa RYLR998

Se decidió utilizar definitivamente el módulo RYLR998 UART en lugar del RFM95CW SPI, por disponibilidad y por la facilidad de configuración mediante comandos AT. Se logró una comunicación parcial usando comandos AT, pero uno de los dos módulos disponibles se dañó durante las pruebas. Actualmente se dispone de un módulo funcional y se está gestionando la adquisición de otro para continuar con la validación entre emisor y receptor.

Figura 4. Módulo LoRa UART RYLR998 utilizado para pruebas de comunicación.

## 4. Avances de la programación

Los avances de programación se organizaron por etapas: prueba de salidas digitales, lectura de sensores, servidor web local, transmisión WiFi y pruebas iniciales con LoRa UART.

## 4.1 Indicadores LED

Se validaron los Leds incorporados de la placa desarrollada, conectados a los GPIO 11, 12 y 13.

Estos fueron utilizados como indicadores de estado:

Indicador | GPIO | Función
LED 1 | GPIO11 | Programa cargado y en ejecución
LED 2 | GPIO12 | Conexión WiFi o estado de comunicación
LED 3 | GPIO13 | Recepción de datos o señal LoRa

Tabla 2. Uso de Leds de depuración en la placa desarrollada.

## 4.2 Librerías utilizadas

Librería / recurso | Uso dentro del proyecto
WiFi | Conexión a redes WiFi y comunicación inalámbrica local.
Webserver | Implementación de servidor web embebido en el ESP32.
Wire | Comunicación I2C con sensores ambientales.
Adafruit_AHTX0.h | Lectura del sensor AHT20/AHT21 para temperatura y humedad.
ScioSense_ENS160.h | Lectura del ENS160 para AQI, TVOC y eCO2.
Hardware Serial | Comunicación UART con módulos RYLR998.

Tabla 3. Librerías y recursos de programación utilizados.

## 4.3 Programa de prueba del sensor con servidor web

Se desarrolló un programa para leer el sensor ENS160 + AHT20/AHT21 mediante I2C y mostrar los datos en una página web local. En la placa ESP32-S3 se utilizaron los pines SDA = GPIO48 y SCL = GPIO47. El programa lee temperatura, humedad, AQI, TVOC y eCO2, y actualiza la página automáticamente cada 5 segundos.

El programa también imprime los valores por Monitor Serial, lo que permitió comprobar la inicialización correcta de los sensores, la versión del ENS160, la IP asignada por la red y los valores medidos.

## 4.4 Programa puente para comandos AT con RYLR998

Para comprobar el módulo RYLR998 se utilizó un programa puente entre el Monitor Serial y el LoRa UART. Esta prueba fue importante porque permitió enviar comandos AT manualmente desde Arduino IDE y observar directamente las respuestas del módulo. La comunicación se realizó con Serial2 a 115200 baudios, usando GPIO16 como RX2 y GPIO17 como TX2.

// ESP32 + RYLR998 - puente AT
#define LORA_RX 16

#define LORA_TX 17

void setup() {
Serial.begin(115200);
Serial2.begin(115200, SERIAL_8N1, LORA_RX, LORA_TX); Serial.println("ESP32 listo para comunicarse con RYLR998"); }

void loop() {
while (Serial2.available()) Serial.write(Serial2.read());
while (Serial.available()) Serial2.write(Serial.read());
}
Con esta prueba se verificó la comunicación básica con el módulo mediante comandos como AT, AT+ADDRESS, AT+NETWORKID, AT+BAND y AT+PARAMETER.

Esta etapa permitió confirmar que el RYLR998 puede ser integrado mediante UART y comandos AT, aunque la validación punto a punto quedó limitada por la falla de uno de los módulos disponibles.

## 4.5 Programa integrado propuesto

A partir de las pruebas aisladas se elaboró un programa integrado para el nodo ambiental. Este código combina la lectura del ENS160 + AHT20/AHT21, impresión de datos por Monitor Serial, servidor web local y envío de una trama LoRa mediante comandos AT al RYLR998. El formato de trama definido para LoRa es:

temperatura;humedad;aqi;tvoc;eco2
Ejemplo: 23.54;78.28;2;69;494

El programa integrado configura el RYLR998 como emisor con ADDRESS=1 y envía datos al receptor configurado con ADDRESS=2. Además, la interfaz web muestra los últimos valores medidos, el estado de WiFi, la última trama LoRa enviada y la respuesta del módulo RYLR998. Esto deja preparado el sistema para completar la comunicación LoRa una vez que se consiga un segundo módulo funcional.

## 4.6 Flujo conceptual del algoritmo final

1. Inicializar el microcontrolador y configurar Leds de estado.
2. Inicializar el bus I2C y detectar el sensor ENS160 + AHT20/AHT21.
3. Leer temperatura y humedad desde el AHT20/AHT21.
4. Compensar el ENS160 con temperatura y humedad.
5. Leer AQI, TVOC y eCO2 desde el ENS160.
6. Validar los datos medidos.
7. Enviar los datos mediante WiFi o LoRa UART según el modo de prueba.
8. Recibir los datos en la placa desarrollada.
9. Actualizar la página web y activar indicadores LED.
10. Repetir el ciclo cada intervalo definido.

## 5. Resultados de pruebas aisladas de sensores y actuadores

Las pruebas aisladas permitieron validar salidas digitales, lectura de sensores, conexión WiFi, servidor web y comunicación inicial con LoRa UART.

## 5.1 Prueba de Leds

Los Leds GPIO11, GPIO12 y GPIO13 funcionaron correctamente y fueron utilizados como indicadores visuales para confirmar programa cargado, conexión WiFi y recepción de datos.

## 5.2 Prueba del sensor ENS160 + AHT20/AHT21

El sensor fue detectado correctamente. En la prueba web y serial se observaron valores coherentes con condiciones de ambiente interior. La inicialización del AHT20 y del ENS160 fue exitosa, y el ENS160 reportó versión 5.4.6.

Variable | Valor observado
Temperatura | 23.16 °C a 23.54 °C
Humedad | 78.28 % a 79.82 %
AQI | 1 a 2
TVOC | 39 ppb a 69 ppb
eCO2 | 434 ppm a 494 ppm
IP observada en prueba web | 192.168.100.186

Tabla 4. Resultados observados durante prueba del sensor y servidor web.

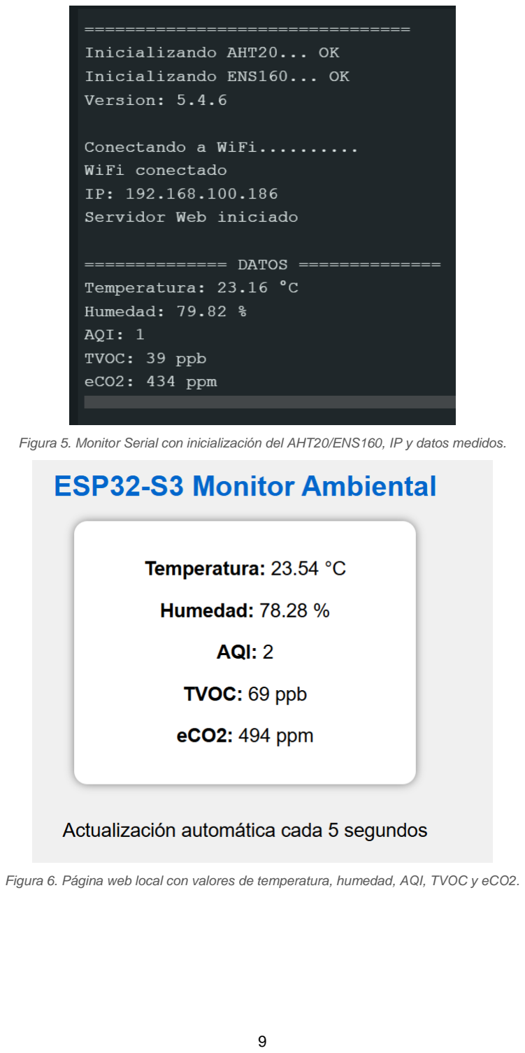
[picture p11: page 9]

Figura 5. Monitor Serial con inicialización del AHT20/ENS160, IP y datos medidos.

Figura 6. Página web local con valores de temperatura, humedad, AQI, TVOC y eCO2.

## 5.3 Prueba de transmisión WiFi

Se validó la transmisión por WiFi utilizando un ESP32 funcional externo como emisor y la placa desarrollada como receptora. El ESP32 emisor realizó la lectura del sensor y envió los datos mediante HTTP GET hacia la placa receptora. La placa receptora mostró los valores en una página web. La IP observada para la placa receptora durante las pruebas en red fue 172.16.253.172.

El formato de envío utilizado fue del tipo: /datos?temp=27.50&hum=60.20&aqi=1&tvoc=25&eco2=420.

## 5.4 Prueba inicial LoRa UART RYLR998

La comunicación LoRa UART se encuentra en etapa de prueba. Se logró comunicación parcial mediante comandos AT usando el programa puente Serial2, confirmando que el enfoque con RYLR998 es viable para el proyecto. Los comandos AT permitieron interactuar con el módulo y verificar su configuración básica. No obstante, uno de los módulos presentó una falla de hardware y se requiere reemplazarlo para completar la prueba punto a punto entre emisor y receptor. La configuración prevista es ADDRESS=1 para el transmisor y ADDRESS=2 para el receptor, manteniendo el mismo NETWORKID, frecuencia y parámetros LoRa.

AT
AT+ADDRESS?
AT+NETWORKID?
AT+BAND?
AT+PARAMETER?
AT+SEND=2, longitud, mensaje

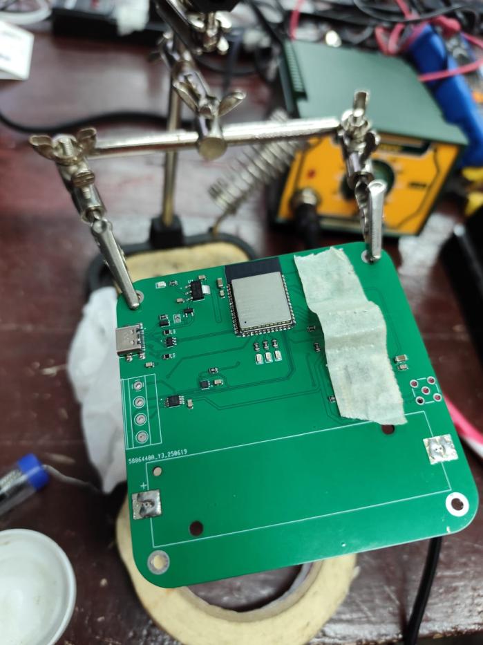
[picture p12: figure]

Figura 7. Terminación de soldadura.

## 6. Estado actual del proyecto

El sistema ya permite medir temperatura, humedad, AQI, TVOC y eCO2 con el sensor ENS160 + AHT20/AHT21, visualizar los datos mediante una página web local y validar la transmisión WiFi.

La comunicación LoRa UART RYLR998 se encuentra aún en etapa de prueba.

La placa desarrollada puede ser alimentada por USB y ejecutar programas cargados por UART. El problema pendiente es el reconocimiento USB para programación directa.

La lectura de sensores, la visualización web y la transmisión WiFi fueron validadas con resultados satisfactorios.

## 7. Conclusiones y recomendaciones

Durante esta etapa se logró avanzar desde el diseño electrónico hacia el montaje, puesta en marcha y validación parcial del prototipo. Se montaron dos placas mediante pasta de soldar, stencil y horno de reflow, complementando el proceso con soldadura manual de headers y botones. Los puentes de soldadura encontrados fueron corregidos mediante cautín y chupa estaño.

Aunque ambas placas desarrolladas presentaron problemas de reconocimiento USB para programación directa, se comprobó que podían alimentarse por USB y ejecutar programas cargados mediante UART. Esta solución permitió continuar con las pruebas funcionales sin detener el avance del proyecto.

Se validó la lectura del sensor ENS160 + AHT20/AHT21 y se obtuvieron valores de temperatura, humedad, AQI, TVOC y eCO2. También se implementó una interfaz web local para visualizar los datos, y se validó la transmisión WiFi entre un ESP32 funcional externo y la placa desarrollada.

La integración LoRa mediante RYLR998 UART queda como etapa pendiente de consolidación. La decisión de utilizar RYLR998 en lugar de RFM95CW se justifica por disponibilidad y simplicidad de integración por UART. Se logró comprobar el uso de comandos AT con un módulo funcional y se desarrolló un programa integrado que combina sensor, página web, Monitor Serial y envío LoRa. Se recomienda conseguir un nuevo módulo funcional, configurar direcciones de transmisor y receptor, y repetir las pruebas de comunicación punto a punto.

Para futuros montajes se recomienda medir continuidad entre 3.3 V y GND antes de alimentar las placas, verificar líneas críticas de programación y comunicación, y realizar una inspección más sistemática del circuito USB antes de la primera prueba de programación.

## 8. Anexos sugeridos

- Fotografías de las PCBs montadas.
- Captura del error de reconocimiento USB en Windows.
- Capturas del Monitor Serial con inicialización y lecturas del sensor.
- Captura de la página web local del ESP32-S3.
- Fotografías del módulo LoRa UART RYLR998.
- Capturas o registros de comandos AT utilizados en la prueba LoRa.
- Esquemáticos del bloque MCU, USB, regulación, LoRa, ADC y monitor de batería.

## Bibliografía

[1] G. Marques and R. Pitarma, “Indoor Air Quality Monitoring Systems for Enhanced Living Environments: A Review toward Sustainable Smart Cities,” Sustainability, vol. 12, no. 10, 2020.
[2] A. Mota et al., “Implementation of an Internet of Things Architecture to Monitor Indoor Air Quality Parameters,” Sensors, vol. 25, no. 6, 2025.
[3] E. González et al., “LoRa Sensor Network Development for Air Quality Monitoring or Detecting Gas Leakage Events,” Sensors, vol. 20, no. 21, 2020.
[4] R. N. Pietraru et al., “Easy-to-Use MOX-Based VOC Sensors for Efficient Indoor Air Quality Monitoring,” Sensors, vol. 24, no. 8, 2024.
[5] ScioSense, “ENS160 Datasheet,” 2023.
[6] Espressif Systems, “ESP32-S3-WROOM-1 / WROOM-1U Datasheet.”
[7] HopeRF, “RFM95CW LoRa Transceiver Module.”
[8] Analog Devices, “MAX17048/MAX17049 Fuel Gauge Datasheet.”
[9] Texas Instruments, “ADS1015 Datasheet.”

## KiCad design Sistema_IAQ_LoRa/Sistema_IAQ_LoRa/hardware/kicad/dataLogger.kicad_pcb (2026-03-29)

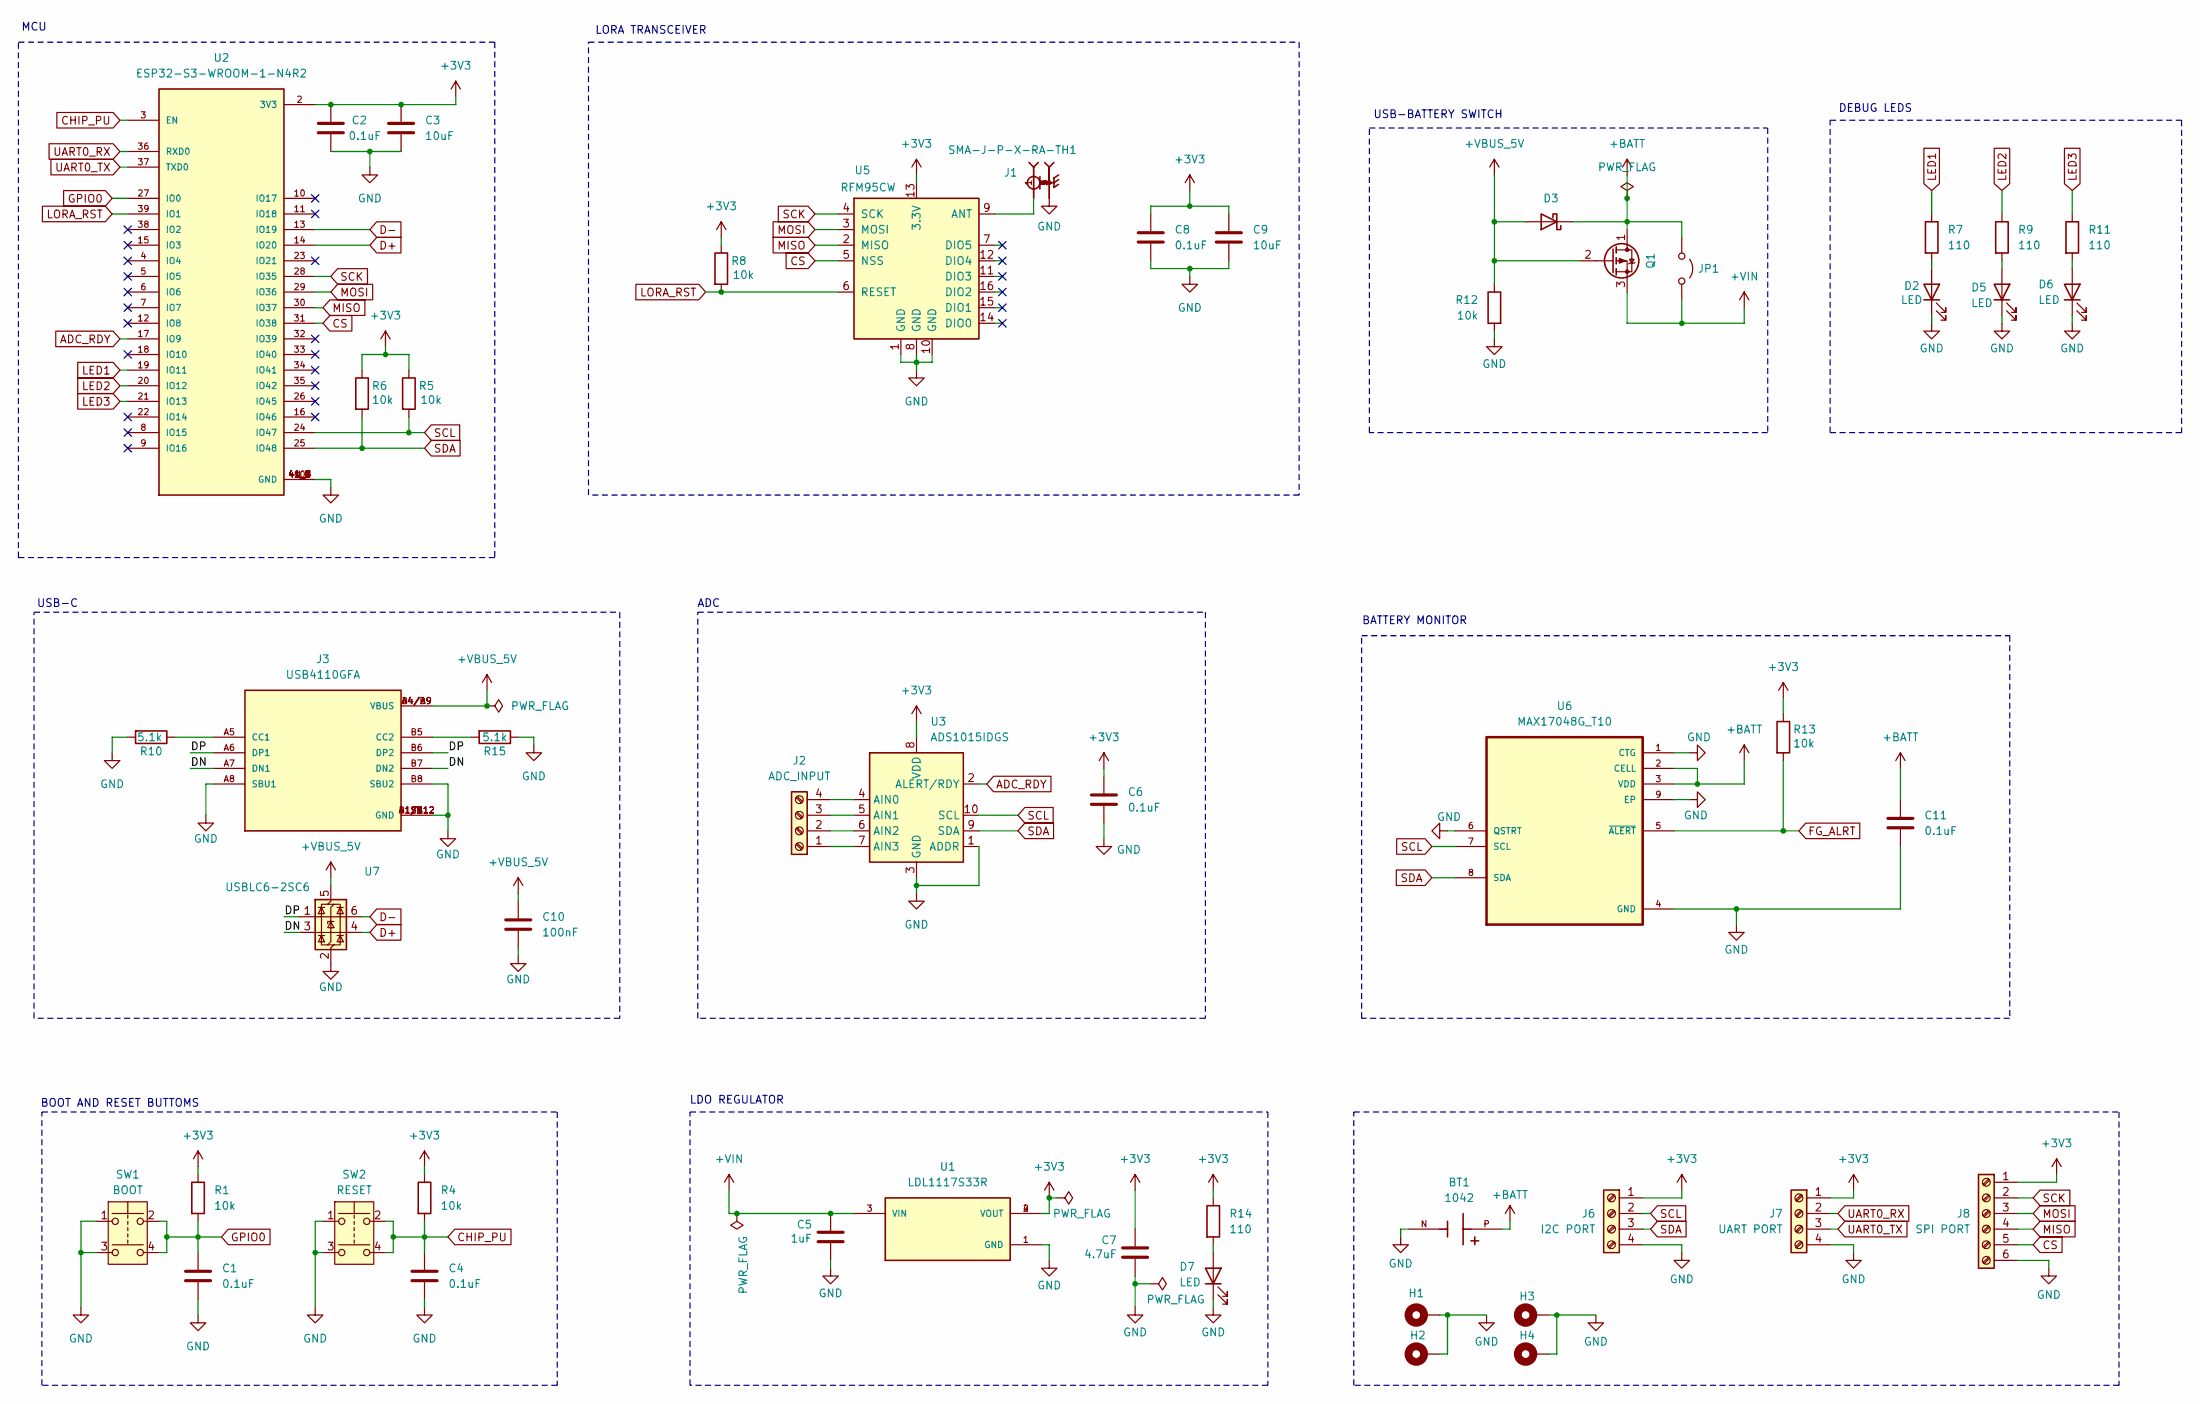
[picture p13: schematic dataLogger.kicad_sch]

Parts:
BT1: 1042; BatteryHolder_Keystone_1042_1x18650; PARTREV E
C1, C2, C4, C6, C8, C11: 0.1uF; C_0805_2012Metric
C3, C9: 10uF; C_0805_2012Metric
C5: 1uF; C_0805_2012Metric
C7: 4.7uF; C_0805_2012Metric
C10: 100nF; C_0805_2012Metric
D2, D5, D6, D7: LED; LED_0805_2012Metric
D3: D_Schottky; D_0805_2012Metric
H1, H2, H3, H4: MountingHole_Pad; MountingHole_3.2mm_M3_DIN965_Pad
J1: SMA-J-P-X-RA-TH1; SAMTEC_SMA-J-P-X-RA-TH1; PARTREV K
J2: ADC_INPUT; TerminalBlock_Phoenix_MKDS-1,5-4-5.08_1x04_P5.08mm_Horizont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
J3: USB4110GFA; GCT_USB4110GFA
J6: I2C PORT; PinHeader_1x04_P2.54mm_Vertical
J7: UART PORT; PinHeader_1x04_P2.54mm_Vertical
J8: SPI PORT; PinHeader_1x06_P2.54mm_Vertical
JP1: Jumper_2_Open; SolderJumper-2_P1.3mm_Open_TrianglePad1.0x1.5mm
Q1: Q_PMOS_DGS; SOT-23
R1, R4, R5, R6, R8, R12, R13: 10k; R_0805_2012Metric
R7, R9, R11, R14: 110; R_0805_2012Metric
R10, R15: 5.1k; R_0805_2012Metric
SW1: BOOT; SW_TS04-66-43-BK-100-SMT
SW2: RESET; SW_TS04-66-43-BK-100-SMT
U1: LDL1117S33R; SOT230P700X180-4N; PARTREV 7
U2: ESP32-S3-WROOM-1-N4R2; XCVR_ESP32-S3-WROOM-1-N4R2; PARTREV v1.0
U3: ADS1015IDGS; SOP50P490X110-10N
U5: RFM95CW; XCVR_RFM95W-868S2
U6: MAX17048G_T10; SON50P200X200X80-9N
U7: USBLC6-2SC6; SOT95P280X145-6N

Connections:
+3V3: C2.1, C3.1, C6.1, C7.1, C8.1, C9.1, J6.1, J7.1, J8.1, R1.1, R4.1, R5.1, R6.1, R8.1, R13.1, R14.1, U1.2 (VOUT), U1.4 (VOUT), U2.2 (3V3), U3.8 (VDD), U5.13 (3.3V)
+BATT: BT1.P, C11.1, D3.1 (K), JP1.1 (A), Q1.1 (D), U6.2 (CELL), U6.3 (VDD)
+VBUS_5V: C10.1, D3.2 (A), J3.A4/B9 (VBUS), J3.B4/A9 (VBUS), Q1.2 (G), R12.1, U7.5 (VBUS)
+VIN: C5.1, JP1.2 (B), Q1.3 (S), U1.3 (VIN)
/DN: J3.A7 (DN1), J3.B7 (DN2), U7.3 (I/O2)
/DP: J3.A6 (DP1), J3.B6 (DP2), U7.1 (I/O1)
ADC_RDY: U2.17 (IO9), U3.2 (ALERT/RDY)
CHIP_PU: C4.1, R4.2, SW2.2, SW2.4, U2.3 (EN)
CS: J8.5, U2.31 (IO38), U5.5 (NSS)
D+: U2.14 (IO20), U7.4 (I/O2)
D-: U2.13 (IO19), U7.6 (I/O1)
FG_ALRT: R13.2, U6.5 (~ALERT)
GND: BT1.N, C1.2, C2.2, C3.2, C4.2, C5.2, C6.2, C7.2, C8.2, C9.2, C10.2, C11.2, D2.1 (K), D5.1 (K), D6.1 (K), D7.1 (K), H1.1, H2.1, H3.1, H4.1, J1.2, J1.3, J1.4, J1.5, J3.A1/B12 (GND), J3.A8 (SBU1), J3.B1/A12 (GND), J3.B8 (SBU2), J3.S1 (GND), J3.S2 (GND), J3.S3 (GND), J3.S4 (GND), J6.4, J7.4, J8.6, R10.2, R12.2, R15.1, SW1.1, SW1.3, SW2.1, SW2.3, U1.1 (GND), U2.1 (GND), U2.40 (GND), U2.41_1 (GND), U2.41_2 (GND), U2.41_3 (GND), U2.41_4 (GND), U2.41_5 (GND), U2.41_6 (GND), U2.41_7 (GND), U2.41_8 (GND), U2.41_9 (GND), U3.1 (ADDR), U3.3 (GND), U5.1 (GND), U5.8 (GND), U5.10 (GND), U6.1 (CTG), U6.4 (GND), U6.6 (QSTRT), U6.9 (EP), U7.2 (GND)
GPIO0: C1.1, R1.2, SW1.2, SW1.4, U2.27 (IO0)
LED1: R7.1, U2.19 (IO11)
LED2: R9.1, U2.20 (IO12)
LED3: R11.1, U2.21 (IO13)
LORA_RST: R8.2, U2.39 (IO1), U5.6 (RESET)
MISO: J8.4, U2.30 (IO37), U5.2 (MISO)
MOSI: J8.3, U2.29 (IO36), U5.3 (MOSI)
unnamed: D2.2 (A), R7.2
unnamed: D5.2 (A), R9.2
unnamed: D6.2 (A), R11.2
unnamed: D7.2 (A), R14.2
unnamed: J2.1, U3.7 (AIN3)
unnamed: J2.2, U3.6 (AIN2)
unnamed: J2.3, U3.5 (AIN1)
unnamed: J2.4, U3.4 (AIN0)
unnamed: J3.A5 (CC1), R10.1
unnamed: J3.B5 (CC2), R15.2
unnamed: J1.1, U5.9 (ANT)
SCK: J8.2, U2.28 (IO35), U5.4 (SCK)
SCL: J6.2, R5.2, U2.24 (IO47), U3.10 (SCL), U6.7 (SCL)
SDA: J6.3, R6.2, U2.25 (IO48), U3.9 (SDA), U6.8 (SDA)
UART0_RX: J7.2, U2.36 (RXD0)
UART0_TX: J7.3, U2.37 (TXD0)

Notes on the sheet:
USB-C
LDO REGULATOR
USB-BATTERY SWITCH
BATTERY MONITOR
LORA TRANSCEIVER
BOOT AND RESET BUTTOMS
DEBUG LEDS
MCU
ADC

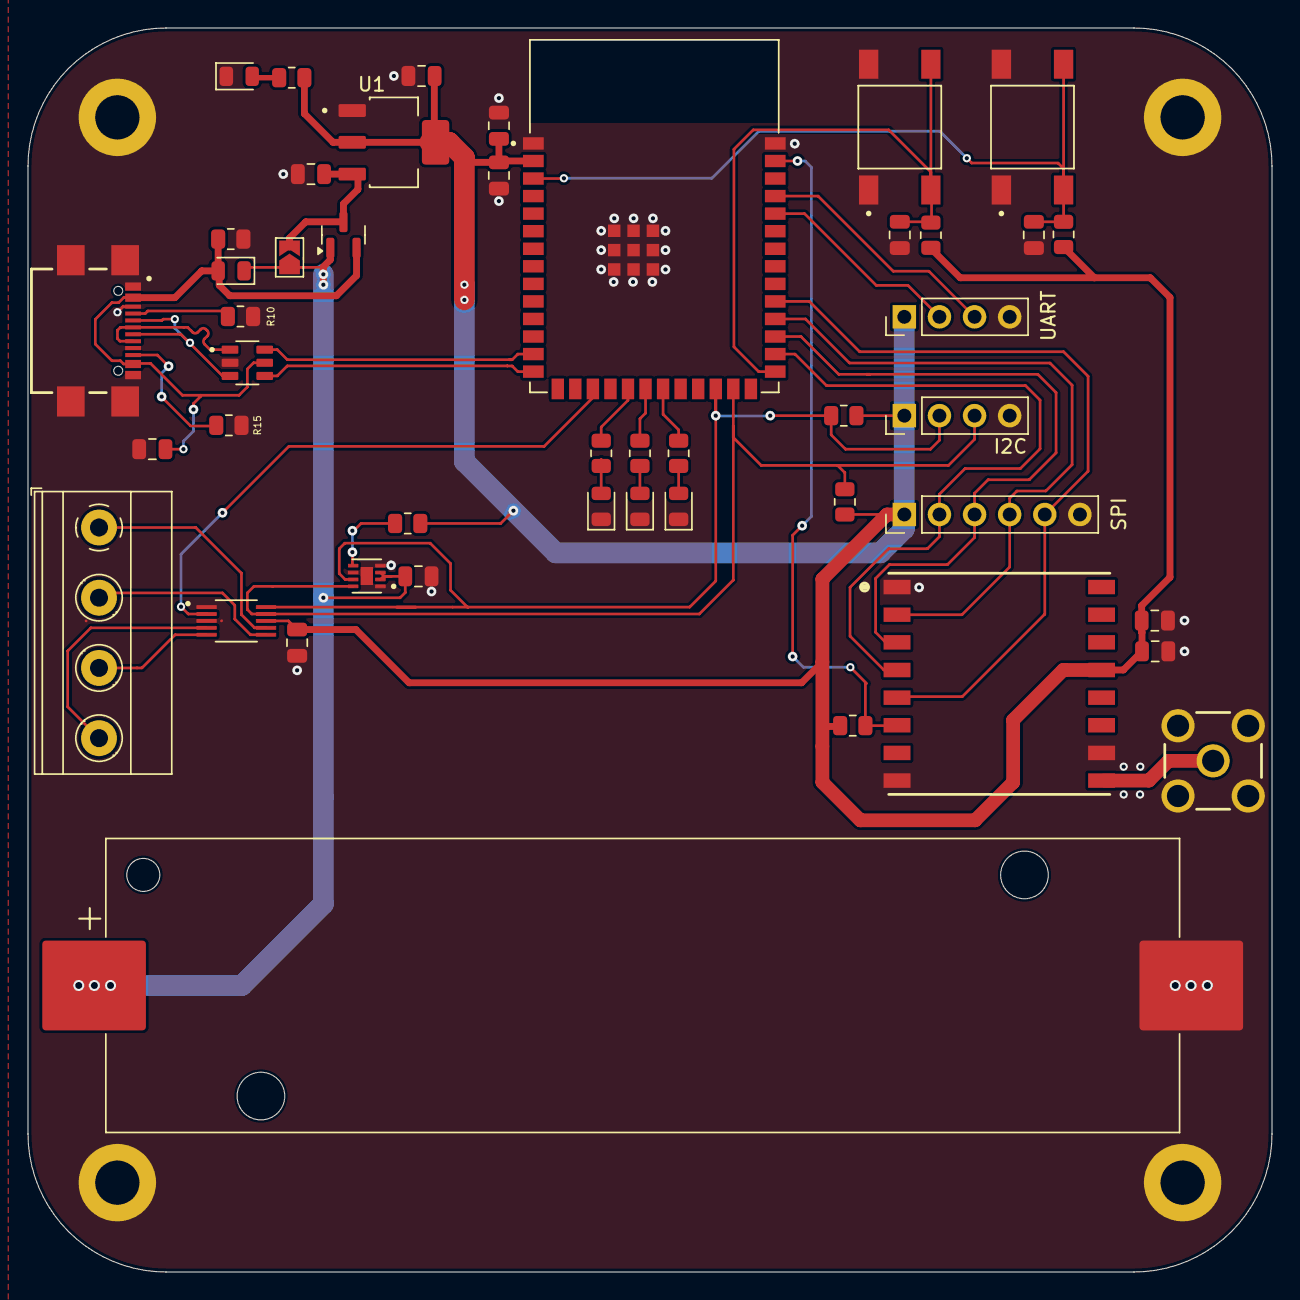
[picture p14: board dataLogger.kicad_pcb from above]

Board: 2 copper layers, 90.0 x 90.0 mm, 50 parts (0 on the bottom side), 36 nets.

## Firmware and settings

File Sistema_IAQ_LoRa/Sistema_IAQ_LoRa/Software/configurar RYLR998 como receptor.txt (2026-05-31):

#define LORA_RX 16
#define LORA_TX 17

void enviarComando(String comando, int espera_ms = 1000) {
  Serial.print(">> ");
  Serial.println(comando);

  Serial2.print(comando);
  Serial2.print("\r\n");

  unsigned long inicio = millis();

  while (millis() - inicio < espera_ms) {
    while (Serial2.available()) {
      char c = Serial2.read();
      Serial.write(c);
    }
  }

  Serial.println();
}

void setup() {
  Serial.begin(115200);
  delay(1000);

  Serial2.begin(115200, SERIAL_8N1, LORA_RX, LORA_TX);

  Serial.println("Configurando RYLR998 como RECEPTOR...");

  enviarComando("AT");
  enviarComando("AT+ADDRESS=2");
  enviarComando("AT+NETWORKID=5");
  enviarComando("AT+BAND=915000000");
  enviarComando("AT+PARAMETER=9,7,1,12");

  Serial.println("Configuracion final:");
  enviarComando("AT+ADDRESS?");
  enviarComando("AT+NETWORKID?");
  enviarComando("AT+BAND?");
  enviarComando("AT+PARAMETER?");
}

void loop() {
  while (Serial2.available()) {
    char c = Serial2.read();
    Serial.write(c);
  }
}

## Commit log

2026-05-31 Update Código de prueba individual LoRa RYLR998 con comandos AT.txt
2026-05-31 Update Código de prueba individual del sensor ENS160 + AHT20AHT21.txt
2026-05-31 Update configurar RYLR998 como emisor.txt
    [configurar RYLR998 como emisor.txt]
2026-05-31 Update configurar RYLR998 como receptor.txt
    [configurar RYLR998 como receptor.txt]
